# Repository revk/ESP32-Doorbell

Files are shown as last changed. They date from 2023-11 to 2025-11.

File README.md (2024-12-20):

## Trademark

This is an open source project, but bear in mind you cannot sell boards bearing the Andrews & Arnold Ltd name, the A&A logo, the registered trademark AJK logo, or the GS1 allocated EANs assigned to Andrews & Arnold Ltd.

# ESP32-Doorbell

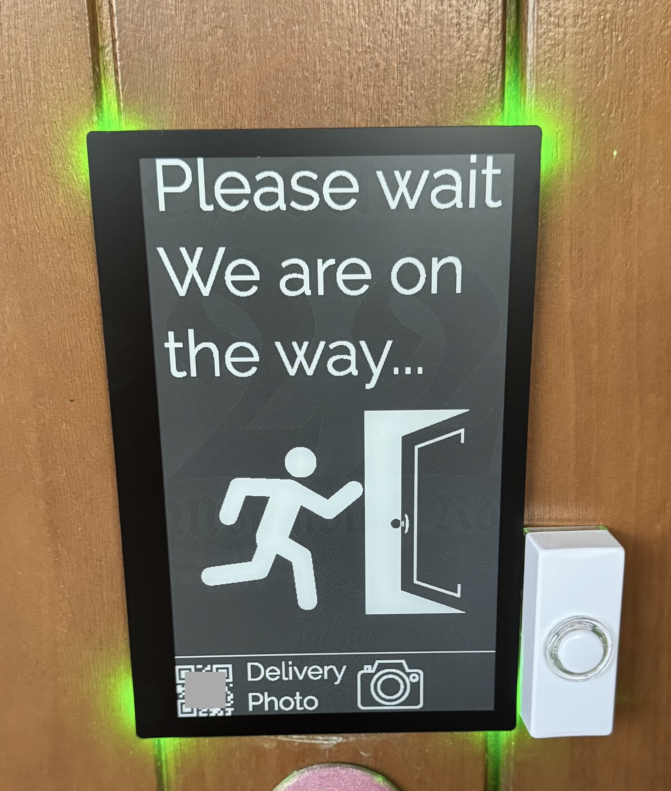
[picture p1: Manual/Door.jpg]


This project is designed to provide an interactive doorbell sign. It can connect to a bell push directly.

The concept is simple, the sign shows a suitable idle message (e.g. house number) but on bell push changes to a different message. The system has automatic seasonal variations on the idle message.

The simple case is a "please wait, we are on the way" messaged to acknowledge the bell push, but it can be customised via web hooks or MQTT or tracking the state of tasmota switches. This means a message could be different when "out" (e.g. leave behind gates, or in secure bin, etc), but without that message on the door all the time.

The bell push itself typically works a bell via MQTT, such as a tasmota switch.

The code runs on an ESP32-S3 and uses the PCB designs from [ESP32-GFX EPD75](https://github.com/revk/ESP32-GFX/tree/main/PCB/EPD75). This includes an LED in each corner and fits the Waveshare 7.5" e-paper. The Waveshare is available with laminated glass front as per this image, and the PCB needs a waterproof coating. Be wary of encasing in resin as the FPC connector can stop working.

[Manual](Manual/Manual.md)

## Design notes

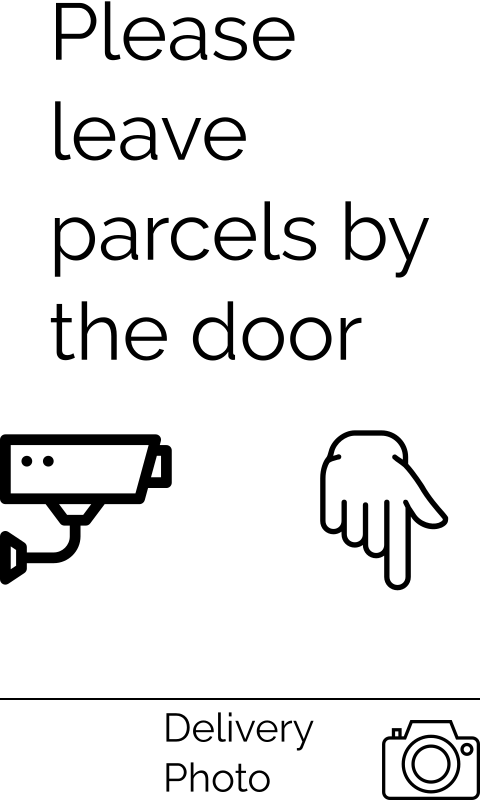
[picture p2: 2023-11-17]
images/Busy.png

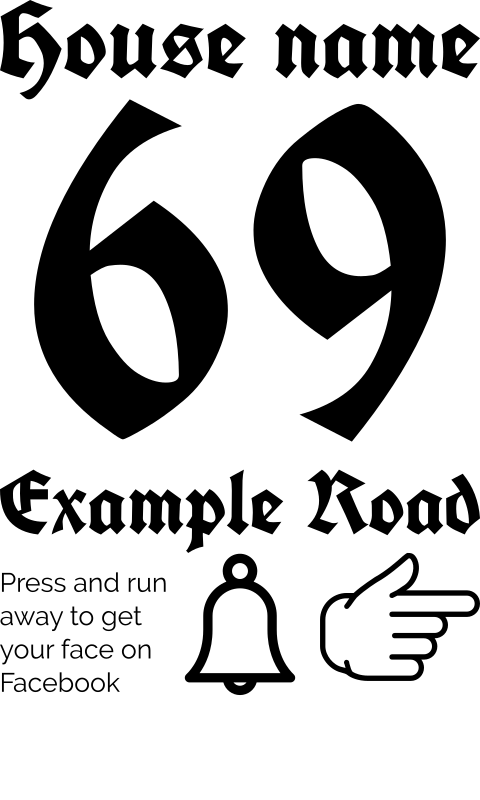
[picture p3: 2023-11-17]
images/Example.png

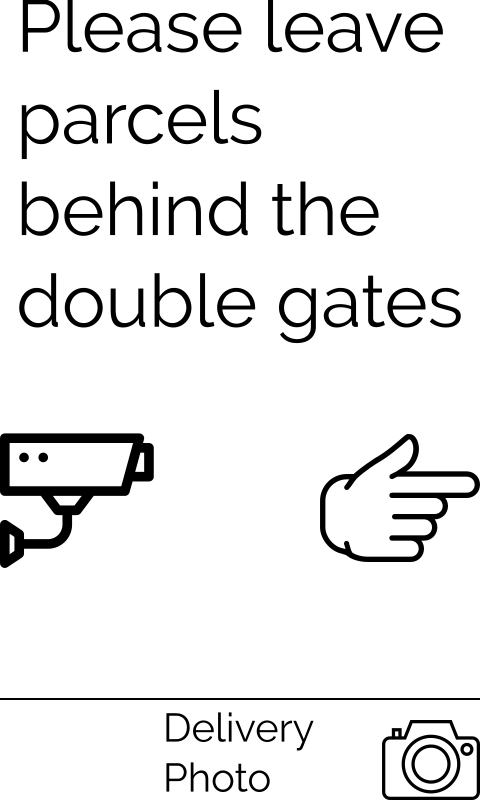
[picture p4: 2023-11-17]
images/Away.png

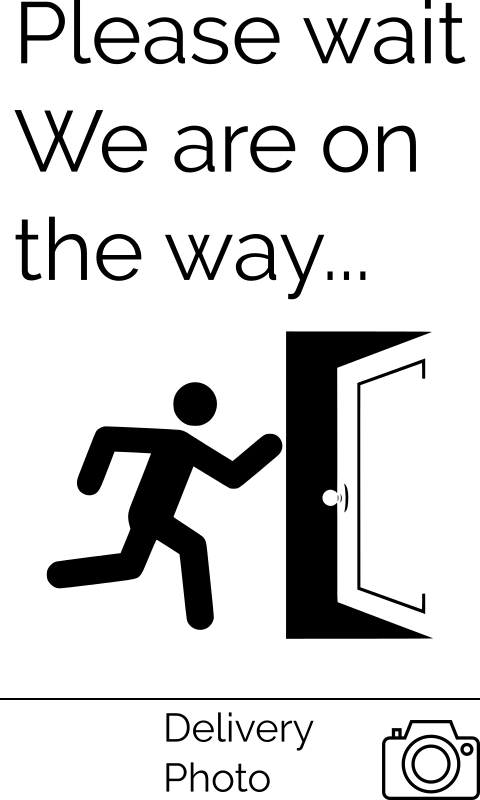
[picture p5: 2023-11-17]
images/Wait.png

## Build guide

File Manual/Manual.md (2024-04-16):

# Manual

## Connections

The [EPD75](https://github.com/revk/ESP32-GFX/tree/main/PCB/EPD75) board has power connections, and pads for `1` and `2` which are two inputs. A bell push, if needed, should be connected to `1`. Power can be via the `+`/`-` pads or USB and can be 5V to 35V.

The PCB sticks directly to the Waveshare 7.5" display, and can easily be mounted to a door with a double layer of gecko tape.

## Basic working

### Idle image

The idle image shows normally, and can be overlaid with a QR code. A small time (HH:MM) is also shown bottom right. The idle image is rechecked from a web server every hour, or if changed for any reason. It also has automatic seasonal adjustments.

|Name|Time period|
|----|---|
|`moon`|12 hours either side of a full moon (takes priority over other settings if `imagemoon` is set)|
|`new`|12 hours either side of a new moon (takes priority over other settings if `imagenew` is set)|
|`year`|1st to 7th Jan|
|`east`|Good Friday to Easter Monday|
|`hall`|From 4pm on 31st Oct|
|`xmas`|1st to 25th Dec|
|`idle`|All other times|

### Active image

When the bell push is pressed, or a `push` MQTT or webhook used, the display changes to the active image which states for a `holdtime` (normally 30 seconds) before reverting to the idle image. This can be a preset active image (set by MQTT or web hook), or can be set automatically based on tracking two tasmota switch states.

|Busy|Away|Name|Example|
|----|----|----|----|
|On|On|`Wait`|Please wait, we are on the way|
|Off|On|`Busy`|We are busy, please leave by the door|
|Any|Off|`Away`|We are not available, please leave somewhere secure|

Note that if the switch state changes whilst the active image is displayed, it changes and the timer restarts.

### QR code

The idle and active images have an overlay of a QR code on the bottom left if the `postcode` setting is set. This encodes the date/time (to minute) and postcode. It is intended for a delivery confirmation photo. Ideally allow 100x100 pixels for this in designs of images. Note a small time (HH:MM) is shown bottom right on the idle image.

## LEDs

The rear LEDs show a colour related to an image - this is by default black (off) when idle and blue when active.

You can prefix any image name with one of more colour letters and a `:`.

Note, you can also prefix the image name (before the colours, if used) with a `*` to force a full flashing refresh.

## Image files

The image files are loaded from a web server. The `imageurl` setting is used to set this. It is recommended that `http://` is used rather than `https://` - this is for performance and memory reasons. For security and reliability it is recommended the server be on the local network, e.g. a Raspberry pi.

The files are loaded from the `imageurl` with `/` and the image name and `.mono`. The image name has any colour prefix removed first. The file itself is expected to be a 48000 byte binary image file for 480 x 800 epaper panel. Note that the panel is normally mounted landscape, so this file needs to have been rotated. To convert an 800x480 `png` to a `mono` file use *ImageMagick*, e.g.

`convert `*sourcepng*` -dither None -monochrome -rotate -90 -depth 1 GRAY:`*targetmono*

Note, the web interface links to the same URL with `.png` to show the current image files.

## MQTT settings

Settings can be changed via MQTT as per the [RevK library](https://github.com/revk/ESP32-RevK). You can change a setting by using the topic `setting/Doorbell`. Not that `Doorbell` is all units, and can instead be the *hostname* or *MAC address* of a specific unit. You can set an individual setting, e.g. `setting/Doorbell/imageidle Example`, or use JSON to set multiple settings, e.g. `setting/Doorbell {"image":{"idle":"Example","xmas":"HoHoHo"}}`

You can see all settings by sending `setting/Doorbell` with no payload. There are a number of settings that are part of the library. There are also a number of GPIO settings not covered here (see the code for these). The main settings are as follows, settings starting `image` and `tas` can be grouped as an object to save space.

|Setting|Meaning|
|---|---|
|`holdtime`|How long to show active image, seconds, default 30|
|`toot`|If set, send an MQTT topic `toot` with payload `@` and the value of this setting whenever bell push activated. Works with `mqttoot` service to send to a mastodon server as a DM|
|`postcode`|Set the postcode to enable the QR code on display|
|`tasbell`|The name of the tasmota device to use for the bell push, it sends `POWER` with `ON` to the device|
|`tasaway`|The name of the tasmota device that is a switch for *away*, if the light is off it is assumed you are away|
|`tasbusy`|The name of the tasmota device that is a switch for *busy*, if the light is off it is assumed you are busy (unless *away*)|
|`imageurl`|The URL for the image files (see above). Default `https://ota.revk.uk/Doorbell`|
|`imageidle`|The name for the idle image by default. Default `Example`|
|`imagexmas`|The name for the idle image at Christmas|
|`imageyear`|The name for the idle image at New Year|
|`imagehall`|The name for the idle image at Halloween|
|`imagewait`|The name for the *wait* state active image when tracking `tasbusy` and/or `tasaway`. Default `Wait`|
|`imagebusy`|The name for the *busy* state active image when tracking `tasbusy` and/or `tasaway`. Default `Busy`|
|`imagewait`|The name for the *away* state active image when tracking `tasbusy` and/or `tasaway`. Default `Away`|

The unit reboots after a setting change.

## MQTT commands

In addition to commands defined in the *RevK* library, there are a number of specific commands that can be sent. They are of the form `command/Doorbell/` and the command name. As above `Doorbell` can be *hostname* or *MAC address* of a specific unit. Some commands take a payload.

|Command|Meaning|
|---|---|
|`active`|Set the current active image name|
|`push`|Activate the bell pushed state and display active message, if a payload is provided this does a one off image display using the payload as image name (and colour prefix)|
|`cancel`|Cancel the current active image and revert to idle image|
|`message`|Display a text message, the payload, separate lines using `/`. This is displated for the current hold time|

## Web hooks

Web hooks allow similar commands without the use of MQTT. These make use of a query string as a parameter if needed.

|URL|Meaning|
|---|---|
|`/push`|Activate the bell pushed state and display active message, if a query is provided this does a one off image display using the payload as image name (and colour prefix)|
|`/active`|Set the current active image name|
|`/message`|Display a text message, the payload, separate lines using `/`. This is displated for the current hold time|

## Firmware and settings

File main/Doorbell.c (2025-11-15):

/* Doorbell app */
/* Copyright ©2019 - 2023 Adrian Kennard, Andrews & Arnold Ltd.See LICENCE file for details .GPL 3.0 */

static const char TAG[] = "Doorbell";

#include "revk.h"
#include "esp_system.h"
#include "esp_timer.h"
#include "esp_sleep.h"
#include "esp_task_wdt.h"
#include "esp_http_client.h"
#include "esp_http_server.h"
#include "esp_crt_bundle.h"
#include "esp_vfs_fat.h"
#include <driver/sdmmc_host.h>
#include <driver/uart.h>
#include "gfx.h"
#include "iec18004.h"
#include <hal/spi_types.h>
#include <driver/gpio.h>
#include <lwpng.h>

#define	UPDATERATE	60

#define	NFCUART	1
#define NFCBUF  280

const char sd_mount[] = "/sd";

httpd_handle_t webserver = NULL;
sdmmc_card_t *card = NULL;
uint32_t pushed = 0;
uint32_t override = 0;
uint32_t last = -1;
char activename[30] = "";
char overridename[30] = "";
led_strip_handle_t strip = NULL;
volatile char led_colour[20] = { 0 };

volatile char overridemsg[1000] = "";

static SemaphoreHandle_t epd_mutex = NULL;

struct
{
   uint8_t mqttinit:1;
   uint8_t wificonnect:1;
   uint8_t tasawaystate:1;
   uint8_t tasbusystate:1;
   uint8_t getimages:1;
   uint8_t btn:1;
} volatile b;

typedef struct file_s
{
   struct file_s *next;         // Next file in chain
   char *url;                   // URL as passed to download
   uint32_t cache;              // Cache until this uptime
   time_t changed;              // Last changed
   uint32_t size;               // File size
   uint32_t w;                  // PNG width
   uint32_t h;                  // PNG height
   uint8_t *data;               // File data
   uint8_t new:1;               // New file
   uint8_t card:1;              // We have tried card
   uint8_t json:1;              // Is JSON
} file_t;

uint8_t nfcled = 0;
uint8_t nfcledoverride = 0;

file_t *cache = NULL;
file_t *idle = NULL;
file_t *idleo = NULL;
file_t *active = NULL;
file_t *activeo = NULL;
char season = 0;

const char *
skipcolour (const char *n)
{
   if (!n || !*n)
      return n;
   if (*n == '!')
      n++;                      // Full refresh
   const char *c = n;
   while (*c && isalpha ((int) (unsigned char) *c))
      c++;                      // Colours
   if (*c == ':')
      n = c + 1;                // Yep, colours (end in :)
   return n;
}

file_t *files = NULL;

file_t *
find_file (char *url)
{
   file_t *i;
   for (i = files; i && strcmp (i->url, url); i = i->next);
   if (!i)
   {
      i = mallocspi (sizeof (*i));
      if (i)
      {
         memset (i, 0, sizeof (*i));
         i->url = strdup (url);
         i->next = files;
         files = i;
      }
   }
   return i;
}

void
check_file (file_t * i)
{
   if (!i || !i->data || !i->size)
      return;
   i->changed = time (0);
   const char *e1 = lwpng_get_info (i->size, i->data, &i->w, &i->h);
   if (!e1)
   {
      i->json = 0;              // PNG
      i->new = 1;
      ESP_LOGE (TAG, "Image %s len %lu width %lu height %lu", i->url, i->size, i->w, i->h);
   } else
   {                            // Not a png
      jo_t j = jo_parse_mem (i->data, i->size);
      jo_skip (j);
      const char *e2 = jo_error (j, NULL);
      jo_free (&j);
      if (!e2)
      {                         // Valid JSON
         i->json = 1;
         i->new = 1;
         i->w = i->h = 0;
         ESP_LOGE (TAG, "JSON %s len %lu", i->url, i->size);
      } else
      {                         // Not sensible
         free (i->data);
         i->data = NULL;
         i->size = 0;
         i->w = i->h = 0;
         i->changed = 0;
         ESP_LOGE (TAG, "Unknown %s error %s %s", i->url, e1 ? : "", e2 ? : "");
      }
   }
}

file_t *
download (char *url)
{
   file_t *i = find_file (url);
   if (!i)
      return i;
   url = strdup (i->url);       // Use as is
   ESP_LOGD (TAG, "Get %s", url);
   int32_t len = 0;
   uint8_t *buf = NULL;
   esp_http_client_config_t config = {
      .url = url,
      .crt_bundle_attach = esp_crt_bundle_attach,
      .timeout_ms = 20000,
   };
   int response = -1;
   if (i->cache > uptime ())
      response = (i->data ? 304 : 404); // Cached
   else if (!revk_link_down () && (!strncasecmp (url, "http://", 7) || !strncasecmp (url, "https://", 8)))
   {
      i->cache = uptime () + imagecache;
      esp_http_client_handle_t client = esp_http_client_init (&config);
      if (client)
      {
         if (i->changed)
         {
            char when[50];
            struct tm t;
            gmtime_r (&i->changed, &t);
            strftime (when, sizeof (when), "%a, %d %b %Y %T GMT", &t);
            esp_http_client_set_header (client, "If-Modified-Since", when);
         }
         if (!esp_http_client_open (client, 0))
         {
            len = esp_http_client_fetch_headers (client);
            ESP_LOGD (TAG, "%s Len %ld", url, len);
            if (!len)
            {                   // Dynamic, FFS
               size_t l;
               FILE *o = open_memstream ((char **) &buf, &l);
               if (o)
               {
                  char temp[64];
                  while ((len = esp_http_client_read (client, temp, sizeof (temp))) > 0)
                     fwrite (temp, len, 1, o);
                  fclose (o);
                  len = l;
               }
               if (!buf)
                  len = 0;
            } else
            {
               buf = mallocspi (len);
               if (buf)
                  len = esp_http_client_read_response (client, (char *) buf, len);
            }
            response = esp_http_client_get_status_code (client);
            if (response != 200 && response != 304)
               ESP_LOGE (TAG, "Bad response %s (%d)", url, response);
            esp_http_client_close (client);
         }
         esp_http_client_cleanup (client);
      }
      ESP_LOGD (TAG, "Got %s %d", url, response);
   }
   if (response != 304)
   {
      if (response != 200)
      {                         // Failed
         jo_t j = jo_object_alloc ();
         jo_string (j, "url", url);
         if (response && response != -1)
            jo_int (j, "response", response);
         if (len == -ESP_ERR_HTTP_EAGAIN)
            jo_string (j, "error", "timeout");
         else if (len)
            jo_int (j, "len", len);
         revk_error ("image", &j);
      }
      if (buf)
      {
         if (i->data && i->size == len && !memcmp (buf, i->data, len))
         {
            free (buf);
            response = 0;       // No change
         } else
         {                      // Change
            free (i->data);
            i->data = buf;
            i->size = len;
            check_file (i);
         }
         buf = NULL;
      }
   }
   if (card)
   {                            // SD
      char *s = strrchr (url, '/');
      if (!s)
         s = url;
      if (s)
      {
         char *fn = NULL;
         if (*s == '/')
            s++;
         asprintf (&fn, "%s/%s", sd_mount, s);
         char *q = fn + sizeof (sd_mount);
         while (*q && isalnum ((int) (uint8_t) * q))
            q++;
         if (*q == '.')
         {
            q++;
            while (*q && isalnum ((int) (uint8_t) * q))
               q++;
         }
         *q = 0;
         if (i->data && response == 200)
         {                      // Save to card
            FILE *f = fopen (fn, "w");
            if (f)
            {
               jo_t j = jo_object_alloc ();
               if (fwrite (i->data, i->size, 1, f) != 1)
                  jo_string (j, "error", "write failed");
               fclose (f);
               jo_string (j, "write", fn);
               revk_info ("SD", &j);
               ESP_LOGE (TAG, "Write %s %lu", fn, i->size);
            } else
               ESP_LOGE (TAG, "Write fail %s", fn);
         } else if (!i->card && (!i->data || (response && response != 304 && response != -1)))
         {                      // Load from card
            i->card = 1;        // card tried, no need to try again
            FILE *f = fopen (fn, "r");
            if (f)
            {
               struct stat s;
               fstat (fileno (f), &s);
               free (buf);
               buf = mallocspi (s.st_size);
               if (buf)
               {
                  if (fread (buf, s.st_size, 1, f) == 1)
                  {
                     if (i->data && i->size == s.st_size && !memcmp (buf, i->data, i->size))
                     {
                        free (buf);
                        response = 0;   // No change
                     } else
                     {
                        ESP_LOGE (TAG, "Read %s", fn);
                        jo_t j = jo_object_alloc ();
                        jo_string (j, "read", fn);
                        revk_info ("SD", &j);
                        response = 200; // Treat as received
                        free (i->data);
                        i->data = buf;
                        i->size = s.st_size;
                        check_file (i);
                     }
                     buf = NULL;
                  }
               }
               fclose (f);
            } else
               ESP_LOGE (TAG, "Read fail %s", fn);
         }
         free (fn);
      }
   }
   free (buf);
   free (url);
   return i;
}

// Image plot

typedef struct plot_s
{
   gfx_pos_t ox,
     oy;
} plot_t;

static void *
my_alloc (void *opaque, uInt items, uInt size)
{
   return mallocspi (items * size);
}

static void
my_free (void *opaque, void *address)
{
   free (address);
}

static const char *
pixel (void *opaque, uint32_t x, uint32_t y, uint16_t r, uint16_t g, uint16_t b, uint16_t a)
{
   plot_t *p = opaque;
   if (a & 0x8000)
      gfx_pixel (p->ox + x, p->oy + y, (g & 0x8000) ? 255 : 0);
   return NULL;
}

void
plot (file_t * i, gfx_pos_t ox, gfx_pos_t oy)
{
   plot_t settings = { ox, oy };
   lwpng_decode_t *p = lwpng_decode (&settings, NULL, &pixel, &my_alloc, &my_free, NULL);
   lwpng_data (p, i->size, i->data);
   const char *e = lwpng_decoded (&p);
   if (e)
      ESP_LOGE (TAG, "PNG fail %s", e);
}

void
image_load (const char *name, file_t * i, char c, uint16_t x, uint16_t y)
{                               // Load image and set LEDs (image can be prefixed with colour, else default is used)
   int n = 0;
   if (name)
   {
      if (*name == '!')
         name++;                // Skip, refresh actually done in calling side
      const char *colours = name;
      while (*colours && isalpha ((int) (unsigned char) *colours))
         colours++;
      if (*colours == ':')
      {                         // Colours
         colours = name;
         while (isalpha ((int) (unsigned char) *colours) && n < sizeof (led_colour))
            led_colour[n++] = *colours++;
      } else if (c)
         led_colour[n++] = c;   // Single from arg
   } else if (c)
      led_colour[n++] = c;      // Single from arg
   if (n)
      while (n < sizeof (led_colour))
         led_colour[n++] = 0;
   if (i && i->data)
   {
      gfx_foreground (imageplot == REVK_SETTINGS_IMAGEPLOT_NORMAL || imageplot == REVK_SETTINGS_IMAGEPLOT_MASK ? 0 : 0xFFFFFF);
      gfx_background (imageplot == REVK_SETTINGS_IMAGEPLOT_NORMAL
                      || imageplot == REVK_SETTINGS_IMAGEPLOT_MASKINVERT ? 0xFFFFFF : 0);
      plot (i, x - i->w / 2, y - i->h / 2);
      gfx_foreground (0);
      gfx_background (0xFFFFFF);
   }
}

file_t *
getimage (const char *name)
{
   name = skipcolour (name);
   if (!name || !*name)
      return NULL;
   char *url = NULL;
   asprintf (&url, "%s/%s.png", imageurl, name);
   char *s = strchr (url, '*');
   if (s)
   {
      if (season)
         *s = season;
      else
         strcpy (s, s + 1);
   }
   file_t *i = find_file (url);
   if (!i || !i->size)
      i = download (url);
   free (url);
   if (!i || !i->size)
      return NULL;
   return i;
}

void
setactive (char *value)
{
   if (!value || !strcmp (activename, value))
      return;
   strncpy (activename, value, sizeof (activename));
   active = NULL;
   if (!last)
      last = -1;                // Redisplay
   if (pushed)
      pushed = uptime () + holdtime;
}

static void
web_head (httpd_req_t * req, const char *title)
{
   revk_web_head (req, title);
   revk_web_send (req, "<style>"        //
                  "body{font-family:sans-serif;background:#8cf;}"       //
                  "</style><body><h1>%s</h1>", title ? : "");
}

static esp_err_t
web_icon (httpd_req_t * req)
{                               // serve image -  maybe make more generic file serve
   extern const char start[] asm ("_binary_apple_touch_icon_png_start");
   extern const char end[] asm ("_binary_apple_touch_icon_png_end");
   httpd_resp_set_type (req, "image/png");
   httpd_resp_send (req, start, end - start);
   return ESP_OK;
}

static esp_err_t
web_text (httpd_req_t * req, const char *msg)
{
   httpd_resp_set_type (req, "text/plain;charset=utf-8");
   if (msg)
      revk_web_send (req, "%s", msg);
   httpd_resp_sendstr_chunk (req, NULL);
   return ESP_OK;
}

void
epd_lock (void)
{
   xSemaphoreTake (epd_mutex, portMAX_DELAY);
   gfx_lock ();
}

void
epd_unlock (void)
{
   gfx_unlock ();
   xSemaphoreGive (epd_mutex);
}
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
void
app_main ()
{
   revk_boot (&app_callback);
   revk_start ();
   epd_mutex = xSemaphoreCreateMutex ();
   xSemaphoreGive (epd_mutex);

   revk_gpio_output (relay, 0);

   revk_task ("push", push_task, NULL, 4);
   revk_task ("nfc", nfc_task, NULL, 4);

   setactive (imagewait);

   if (leds)
   {
      led_strip_config_t strip_config = {
         .strip_gpio_num = (rgb.num),
         .max_leds = leds,
         .color_component_format = LED_STRIP_COLOR_COMPONENT_FMT_GRB,
         .led_model = LED_MODEL_WS2812, // LED strip model
         .flags.invert_out = rgb.invert,
      };
      led_strip_rmt_config_t rmt_config = {
         .clk_src = RMT_CLK_SRC_DEFAULT,        // different clock source can lead to different power consumption
         .resolution_hz = 10 * 1000 * 1000,     // 10MHz
         .flags.with_dma = true,
      };
      REVK_ERR_CHECK (led_strip_new_rmt_device (&strip_config, &rmt_config, &strip));
      if (strip)
         revk_task ("led", led_task, NULL, 4);
      image_load (NULL, NULL, 'M', gfx_width () / 2, gfx_height () / 2);
   }
   // Web interface
   httpd_config_t config = HTTPD_DEFAULT_CONFIG ();
   config.stack_size += 1024 * 4;
   config.lru_purge_enable = true;
   config.max_uri_handlers = 6 + revk_num_web_handlers ();
   if (!httpd_start (&webserver, &config))
   {
      register_get_uri ("/", web_root);
      register_get_uri ("/apple-touch-icon.png", web_icon);
      register_get_uri ("/push", web_push);
      register_get_uri ("/message", web_message);
      register_get_uri ("/active", web_active);
#ifdef	CONFIG_LWPNG_ENCODE
      if (gfx_bpp () == 1)
         register_get_uri ("/frame.png", web_frame);
#endif
      revk_web_settings_add (webserver);
   }
   {
    const char *e = gfx_init (cs: gfxcs.num, sck: gfxsck.num, mosi: gfxmosi.num, dc: gfxdc.num, rst: gfxrst.num, busy: gfxbusy.num, ena: gfxena.num, flip: gfxflip, direct: 1, invert:gfxinvert);
      if (e)
      {
         ESP_LOGE (TAG, "gfx %s", e);
         jo_t j = jo_object_alloc ();
         jo_string (j, "error", "Failed to start");
         jo_string (j, "description", e);
         revk_error ("gfx", &j);
      }
      xSemaphoreTake (epd_mutex, portMAX_DELAY);
      revk_gfx_init (startup);
      xSemaphoreGive (epd_mutex);
   }
   if (sdcmd.set)
   {
      revk_gpio_input (sdcd);
      sdmmc_slot_config_t slot = SDMMC_SLOT_CONFIG_DEFAULT ();
      slot.clk = sdclk.num;
      slot.cmd = sdcmd.num;
      slot.d0 = sddat0.num;
      slot.d1 = sddat1.set ? sddat1.num : -1;
      slot.d2 = sddat2.set ? sddat2.num : -1;
      slot.d3 = sddat3.set ? sddat3.num : -1;
      //slot.cd = sdcd.set ? sdcd.num : -1; // We do CD, and not sure how we would tell it polarity
      slot.width = (sddat2.set && sddat3.set ? 4 : sddat1.set ? 2 : 1);
      if (slot.width == 1)
         slot.flags |= SDMMC_SLOT_FLAG_INTERNAL_PULLUP; // Old boards?
      sdmmc_host_t host = SDMMC_HOST_DEFAULT ();
      host.max_freq_khz = SDMMC_FREQ_HIGHSPEED;
      host.slot = SDMMC_HOST_SLOT_1;
      esp_vfs_fat_sdmmc_mount_config_t mount_config = {
         .format_if_mount_failed = 1,
         .max_files = 2,
         .allocation_unit_size = 16 * 1024,
         .disk_status_check_enable = 1,
      };
      if (esp_vfs_fat_sdmmc_mount (sd_mount, &host, &slot, &mount_config, &card))
      {
         jo_t j = jo_object_alloc ();
         ESP_LOGE (TAG, "SD Mount failed");
         jo_string (j, "error", "Failed to mount");
         revk_error ("SD", &j);
         card = NULL;
      } else
         ESP_LOGE (TAG, "SD Mounted");
   }

   void flash (void)
   {                            // Random data
      uint32_t r = 0;
      epd_lock ();
      for (int y = 0; y < gfx_height (); y++)
         for (int x = 0; x < gfx_width (); x++)
         {
            if (!(x & 31))
               r = esp_random ();
            gfx_pixel (x, y, (r & 1) ? 255 : 0);
            r >>= 1;
         }
      gfx_refresh ();
      epd_unlock ();
   }
   if (gfxflash)
      flash ();

   uint32_t lastrefresh = 0;
   while (1)
   {
      usleep (100000);
      time_t now = time (0) + 2;
      struct tm t;
      localtime_r (&now, &t);
      uint32_t up = uptime ();
      void addqr (int active)
      {
         char temp[200];
         sprintf (temp, "%4d-%02d-%02d %02d:%02d %s", t.tm_year + 1900, t.tm_mon + 1, t.tm_mday, t.tm_hour, t.tm_min, postcode);
         gfx_pos (0, gfx_height () - 1, GFX_B | GFX_L | GFX_V);
         gfx_qr (temp, 4);
         if (active >= 0)
         {
            gfx_pos (gfx_width () - 2, gfx_height () - 2, GFX_R | GFX_B | GFX_V);       // Yes slightly in from edge
#if	UPDATERATE >= 60
            gfx_7seg (0, active > 0 ? 4 : 2, "%02d:%02d", t.tm_hour, t.tm_min);
#else
            gfx_7seg (0, active > 0 ? 3 : 2, "%02d:%02d:%02d", t.tm_hour, t.tm_min, t.tm_sec);
#endif
            if (active > 0)
            {
               gfx_7seg (0, 2, "%02d-%02d", t.tm_mon + 1, t.tm_mday);
               gfx_7seg (0, 2, "%04d-", t.tm_year + 1900);
            }
         }
      }
      if (b.mqttinit)
      {
         ESP_LOGE (TAG, "MQTT Connected");
         b.mqttinit = 0;
         last = -1;
         tassub (tasaway);
         tassub (tasbusy);
      }
      if (b.getimages)
      {                         // Ensure images in cache in advance
         b.getimages = 0;
         getimage (imageidle);
         idleo = getimage (imageidleo);
         activeo = getimage (imageactiveo);
         getimage (imagewait);
         if (*tasbusy)
            getimage (imagebusy);
         if (*tasaway)
            getimage (imageaway);
      }
      if (b.wificonnect)
      {
         b.wificonnect = 0;
         b.getimages = 1;
         last = 0;
      }
      if (*overridemsg)
      {
         ESP_LOGE (TAG, "Override: %s", overridemsg);
         if (override < up)
            override = up + holdtime;
         last = 0;
         epd_lock ();
         gfx_clear (0);
         gfx_message ((char *) overridemsg);
         *overridemsg = 0;
         addqr (-1);
         epd_unlock ();
      }
      if (*overridename)
      {                         // Special override
         ESP_LOGE (TAG, "Override: %s", overridename);
         char *t = strdup (overridename);
         *overridename = 0;
         file_t *i = getimage (t);
         if (i)
         {
            if (override < up)
               override = up + holdtime;
            last = 0;
            if (*t == '!')
               gfx_refresh ();
            epd_lock ();
            gfx_clear (0);
            image_load (t, i, 'B', gfx_width () / 2, gfx_height () / 2);
            addqr (-1);
            epd_unlock ();
         }
         free (t);
      }
      if (override && override < up)
         override = 0;
      if (override)
         continue;
      if (pushed < up)
         pushed = 0;            // Time out
      if (pushed)
      {                         // Bell was pushed
         if (last)
         {                      // Show, and reinforce image
            if (last)
            {
               if (relay.set)
                  revk_gpio_set (relay, 1);
               if (*tasbell)
               {
                  char *topic = NULL;
                  asprintf (&topic, "cmnd/%s/POWER", tasbell);
                  revk_mqtt_send_raw (topic, 0, "ON", 1);
                  free (topic);
               }
               const char *msg = b.tasawaystate ? mqttaway : b.tasbusystate ? mqttbusy : mqttbell;
               if (*msg)
                  revk_mqtt_send_str (msg);
               if (*toot)
               {
                  char *pl = NULL;
                  asprintf (&pl, "@%s\nDing dong\n%s\n%4d-%02d-%02d %02d:%02d:%02d", toot, activename, t.tm_year + 1900,
                            t.tm_mon + 1, t.tm_mday, t.tm_hour, t.tm_min, t.tm_sec);
                  revk_mqtt_send_raw ("toot", 0, pl, 1);
                  free (pl);
               }
            }
            if (!active)
               active = getimage (activename);
            epd_lock ();
            if (imageflash)
               gfx_refresh ();
            gfx_clear (0);
            if (!active)
               gfx_message ("/ / / / / / /[11]PLEASE/WAIT");
            else
               image_load (activename, active, 'B', gfx_width () / 2, gfx_height () / 2);
            image_load (imageactiveo, activeo, 0, imageactivex, imageactivey);
            if (last && *activename == '!')
               gfx_refresh ();
            addqr (1);
            epd_unlock ();
            if (last && relay.set)
               revk_gpio_set (relay, 0);
            // Update for cache if changes
            active = getimage (activename);
            activeo = getimage (imageactiveo);
            last = 0;
            b.getimages = 1;
         }
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

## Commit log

2023-11-18 Started, but need a face up sockedt
    [EPD75.kicad_pcb, EPD75.kicad_sch, bom.csv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]
2023-11-18 Better connector
    [EPD75.kicad_pcb, EPD75.kicad_sch, bom.csv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]
2023-11-19 Needs tracking
    [EPD75.kicad_pcb, EPD75.kicad_sch, bom.csv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]
2023-11-19 Initial tracking
    [EPD75.kicad_pcb, EPD75.kicad_sch, bom.csv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]
2023-11-19 50V caps
    [EPD75.kicad_pcb, EPD75.kicad_sch, bom.csv]
2023-11-19 Started on simple board
    [EPD.kicad_pcb, EPD.kicad_sch, EPD75.kicad_pcb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]
2023-11-19 Silk tweak
    [EPD75.kicad_pcb]
2023-11-21 Allow for NFC
    [EPD75.kicad_pcb, positions.csv]
2023-11-21 Moved power reg
    [EPD75.kicad_pcb, positions.csv]
2023-11-21 Track clean
    [EPD75.kicad_pcb]
2023-11-21 More general EPD driver
    [EPD.kicad_pcb, EPD.kicad_sch, bom.csv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]
2023-11-23 Product code
    [EPD.kicad_pcb]
2023-11-23 Moved PCB to GFX
    [EPD.kicad_pcb, EPD.kicad_sch, EPD75.kicad_pcb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]
2024-01-11 mutex... But still no clue why crashed
    [Doorbell.c]
2024-12-19 NFC LED state tracking
2024-12-20 NFC monitoring and LED logic
2025-03-02 No reinforce, done by gfx now
    [Doorbell.c]
2025-03-06 Start on frame logic
2025-03-06 Show current frame buffer
2025-03-06 Frame view
